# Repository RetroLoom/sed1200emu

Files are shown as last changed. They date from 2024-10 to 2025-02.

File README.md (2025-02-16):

# SED1200Emu
This Emulator is intended to replace hard-to-obtain Epson SED1200 based LCD modules with common HD44780 ones. The original project page can be found here http://sensi.org/~tnt23/sed1200emu/index.html. The original goal is for having a replacement LCD for the Roland MT-32, but the display could be adapted for other projects. All attempts to reach the original designer have failed. Please reach out to me if you have any information about this. 

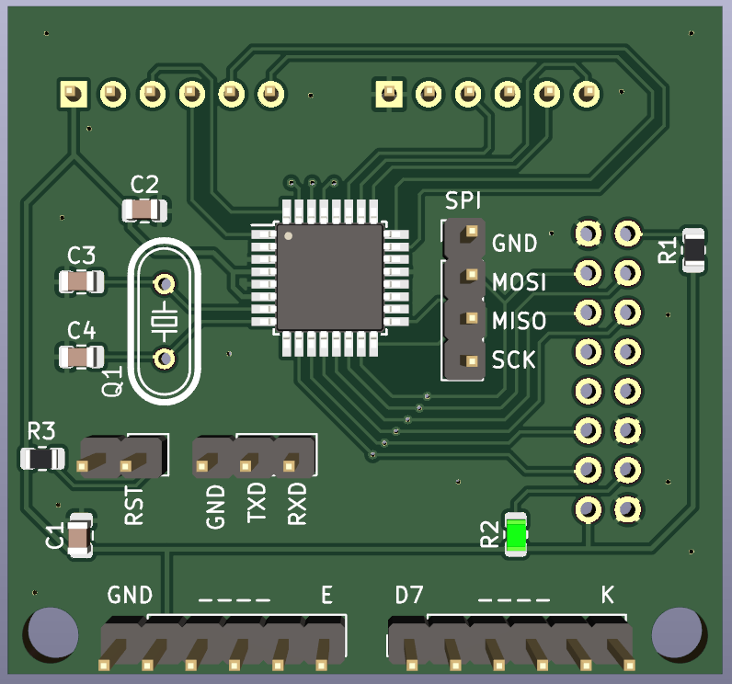
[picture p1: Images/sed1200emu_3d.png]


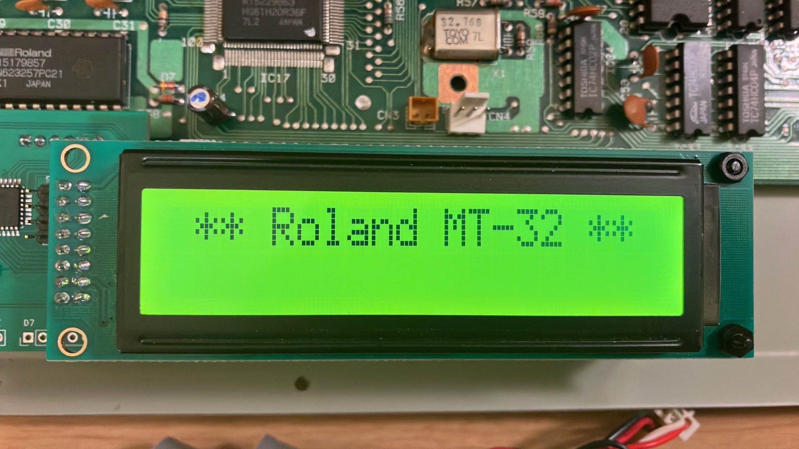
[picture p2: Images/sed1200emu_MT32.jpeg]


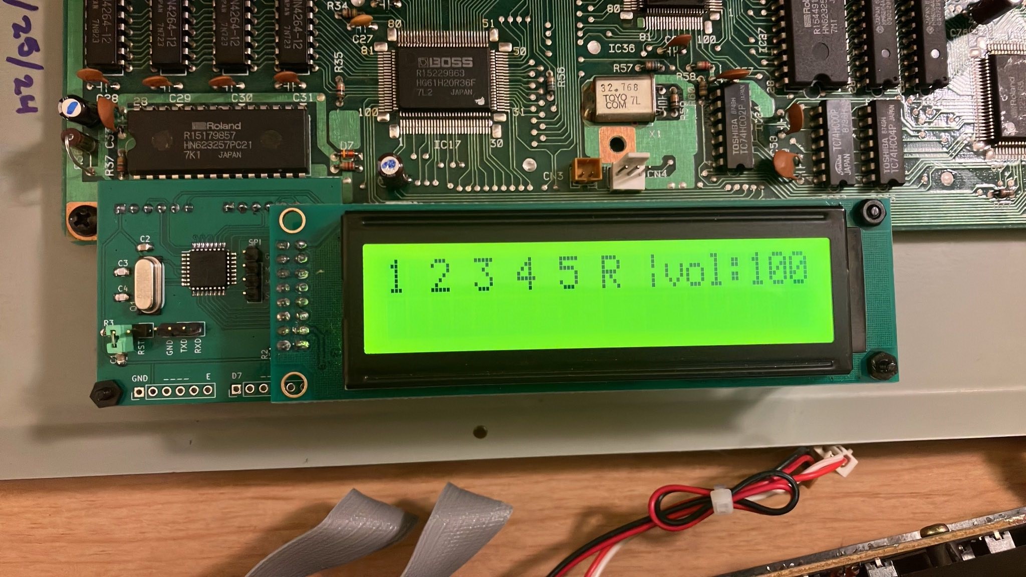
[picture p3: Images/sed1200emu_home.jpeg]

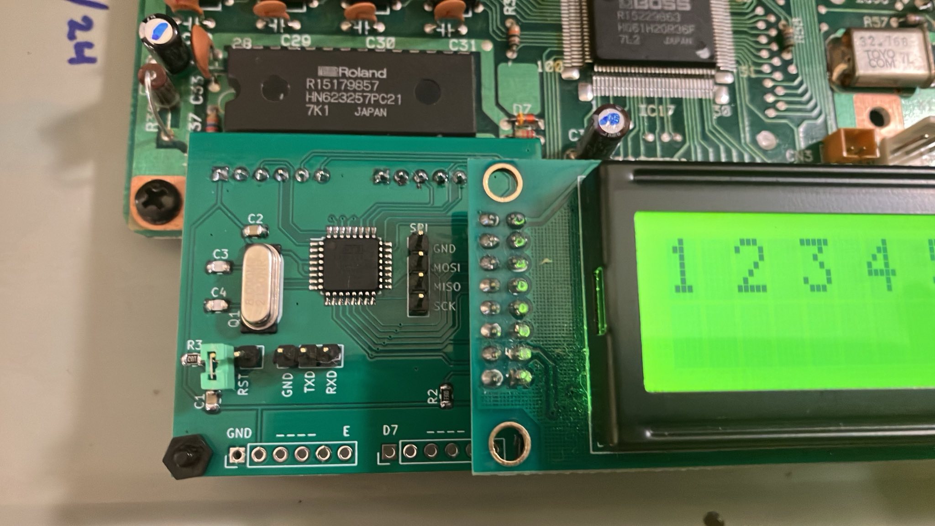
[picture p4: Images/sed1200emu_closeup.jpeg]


## Building and Installation
The main driver and translator for this project is an ATMEGA8L-8AU which can still be purchased on popular sites like Mouser and Digi-key. This IC may become obsolete, so the intention is to adapt as they become less available. The gerber files, BOM, Binary HEX files will also be provided as they become current and available. All current releases are in beta, and come with no warranty. 

### ATMEGA8 Flashing
When programming the ATMEGA8 it is important to use the correct configuration. This will enable the external clocks and any other flags needed for binary to run correctly. 

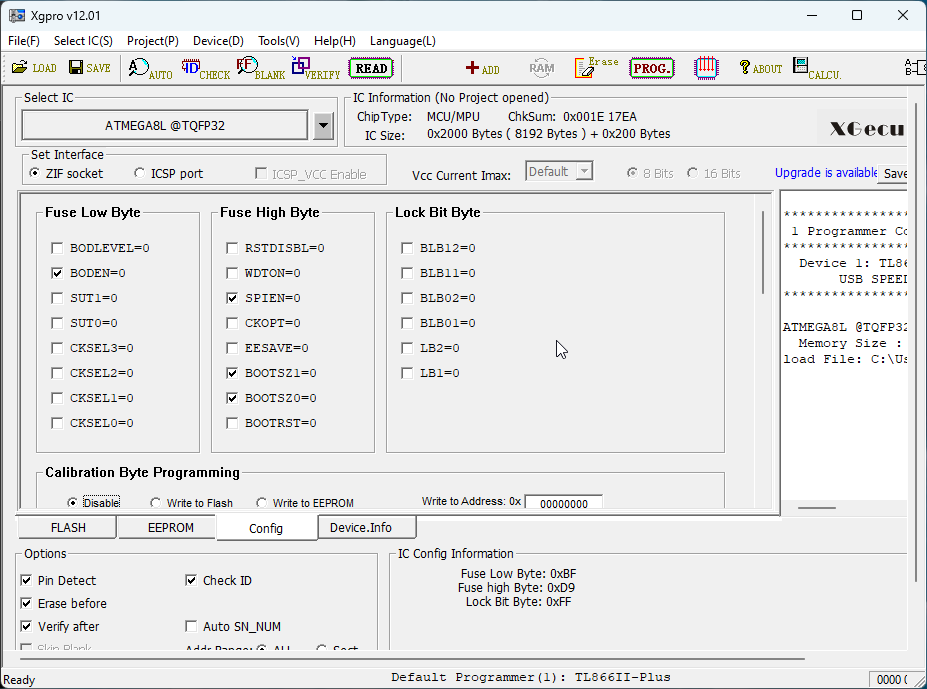
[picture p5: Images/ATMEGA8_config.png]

Fuse Low Byte: 0xBF

Fuse High Bte: 0xD9

Lock Bit Byte: 0xFF

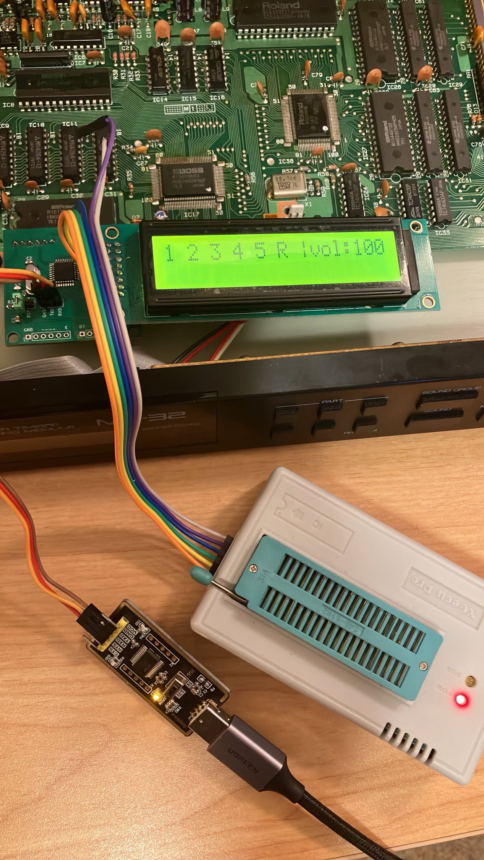
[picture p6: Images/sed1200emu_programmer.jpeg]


### Compiling
Download and install WinAVR for minimum compiling support. Using command prompt or windows powershell, run make in the src directory.

Note: You can optionally replace the AVR compiling files to manually update to newer versions. 

### UART Config
For debugging or logging display message, connect via serial to GND, TXD, RXD at 9600 baud.
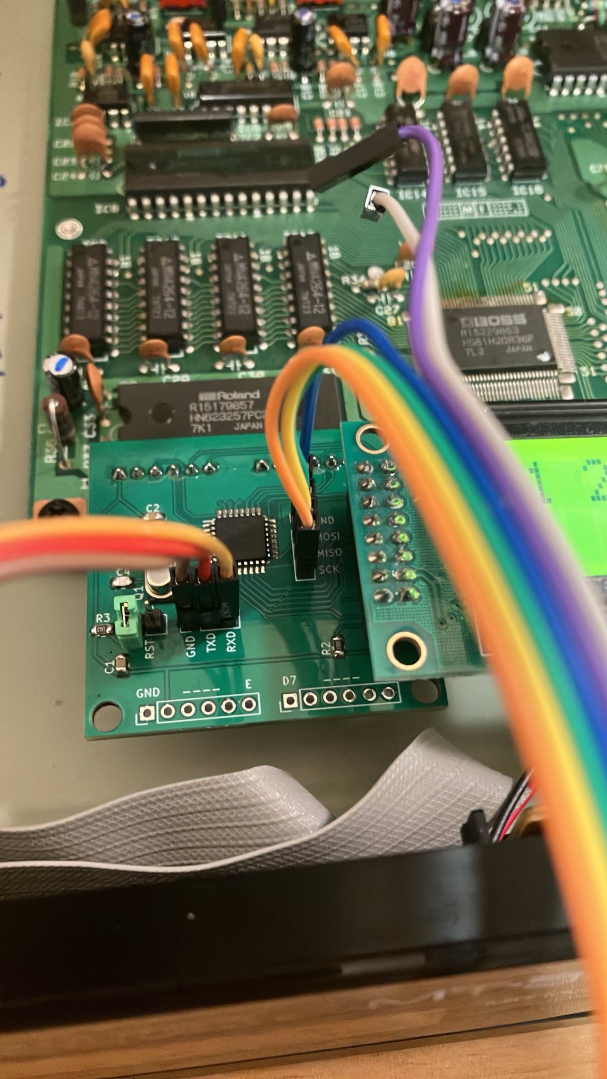
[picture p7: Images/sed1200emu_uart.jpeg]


UART Serial out display clone (and debugging).



### Optional Headers
There are three headers that are considered optional, but recommended if you are developing or want to reprogram the ATMEGA8 after it is soldered to the board. The SPI header will provide connection for flashing, and the UART header will give you access to feedback and debug information for code development. 

## Development Notes
At the moment, 20x2 HD44780 LCD is too large as a direct replacement for the MT-32. Adaptation will be needed in the form of a redesigned 3D printed face plate for the current LCD. If you have interest in helping design something like this, please get in touch! I have searched around for better fitting 20x2 LCD's but I have not found anything that would match. 

Another option is to program new methods that adapts the display to a 16x2 LCD. This might need some elaborate programming to work. 

## License Information
The original release this project is derived from Tim Tashpulatov without license or warranty. The updated revisions of this project released in 2024 include a GPL v3 license which can be found here in the LICENSE file. 

Source code and software license - [GPL v3](https://github.com/skadarnold/sed1200emu/blob/master/LICENSE)

Hardware design license - [CERN OHL-S](https://ohwr.org/project/cernohl/-/wikis/uploads/819d71bea3458f71fba6cf4fb0f2de6b/cern_ohl_s_v2.txt)

## Support the Developer
This project is brought to you free and open source, but it is not free to develop. If you like this project please consider supporting this and future developments. 

https://www.patreon.com/RetroLoom

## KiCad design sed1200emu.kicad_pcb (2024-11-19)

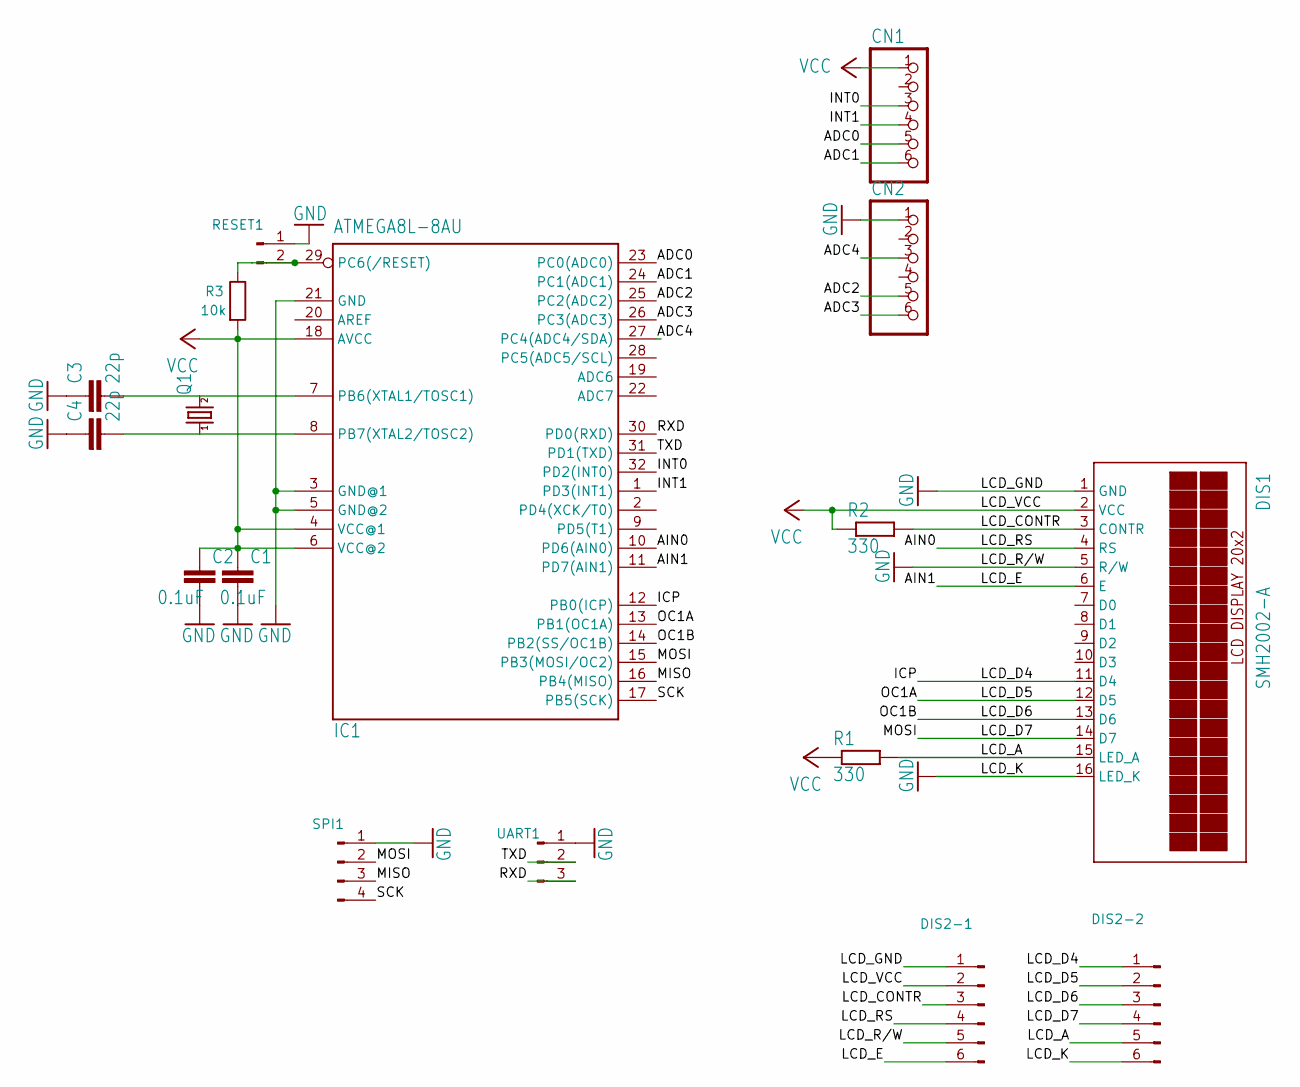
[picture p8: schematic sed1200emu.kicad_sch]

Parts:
C1, C2: 0.1uF; C_0805_2012Metric
C3, C4: 22p; C_0805_2012Metric
CN1, CN2: Conn_01x06_Pin 2.54mm; PinHeader_1x06_P2.54mm_Vertical
DIS1: SMH2002-A; TUXGR_20X2
DIS2-1, DIS2-2: Conn_01x06_Pin; PinHeader_1x06_P2.54mm_Vertical
IC1: ATMEGA8L-8AU; TQFP-32_7x7mm_P0.8mm
Q1: HC-49/S 16pF; HC49_S
R1, R2: 330; R_0805_2012Metric
R3: 10k; R_0805_2012Metric
RESET1: Conn_01x02_Pin; PinHeader_1x02_P2.54mm_Vertical
SPI1: Conn_01x04_Pin; PinHeader_1x04_P2.54mm_Vertical
UART1: Conn_01x03_Pin; PinHeader_1x03_P2.54mm_Vertical

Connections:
/ADC0: CN1.5, IC1.23 (PC0(ADC0))
/ADC1: CN1.6, IC1.24 (PC1(ADC1))
/ADC2: CN2.5, IC1.25 (PC2(ADC2))
/ADC3: CN2.6, IC1.26 (PC3(ADC3))
/ADC4: CN2.3, IC1.27 (PC4(ADC4/SDA))
/AIN0: DIS1.4 (RS), DIS2-1.4, IC1.10 (PD6(AIN0))
/AIN1: DIS1.6 (E), DIS2-1.6, IC1.11 (PD7(AIN1))
/ICP: DIS1.11 (D4), DIS2-2.1, IC1.12 (PB0(ICP))
/INT0: CN1.3, IC1.32 (PD2(INT0))
/INT1: CN1.4, IC1.1 (PD3(INT1))
/LCD_A: DIS1.15 (LED_A), DIS2-2.5, R1.2
/LCD_CONTR: DIS1.3 (CONTR), DIS2-1.3, R2.2
/LCD_D5: DIS1.12 (D5), DIS2-2.2, IC1.13 (PB1(OC1A))
/LCD_D6: DIS1.13 (D6), DIS2-2.3, IC1.14 (PB2(SS/OC1B))
/LCD_D7: DIS1.14 (D7), DIS2-2.4, IC1.15 (PB3(MOSI/OC2)), SPI1.2
/MISO: IC1.16 (PB4(MISO)), SPI1.3
/RXD: IC1.30 (PD0(RXD)), UART1.3
/SCK: IC1.17 (PB5(SCK)), SPI1.4
/TXD: IC1.31 (PD1(TXD)), UART1.2
GND: C1.2, C2.2, C3.1, C4.1, CN2.1, DIS1.1 (GND), DIS1.5 (R/W), DIS1.16 (LED_K), DIS2-1.1, DIS2-1.5, DIS2-2.6, IC1.3 (GND@1), IC1.5 (GND@2), IC1.21 (GND), RESET1.1, SPI1.1, UART1.1
unnamed: C3.2, IC1.7 (PB6(XTAL1/TOSC1)), Q1.2
unnamed: C4.2, IC1.8 (PB7(XTAL2/TOSC2)), Q1.1
unnamed: IC1.29 (PC6(/RESET)), R3.1, RESET1.2
VCC: C1.1, C2.1, CN1.1, DIS1.2 (VCC), DIS2-1.2, IC1.4 (VCC@1), IC1.6 (VCC@2), IC1.18 (AVCC), R1.1, R2.1, R3.2

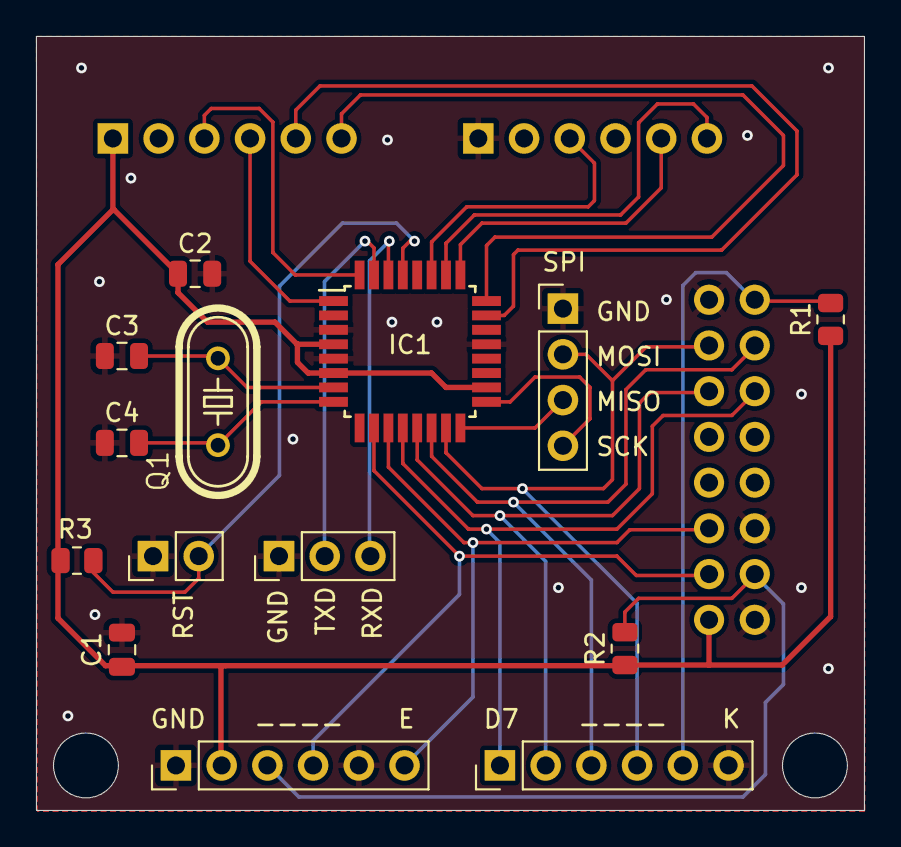
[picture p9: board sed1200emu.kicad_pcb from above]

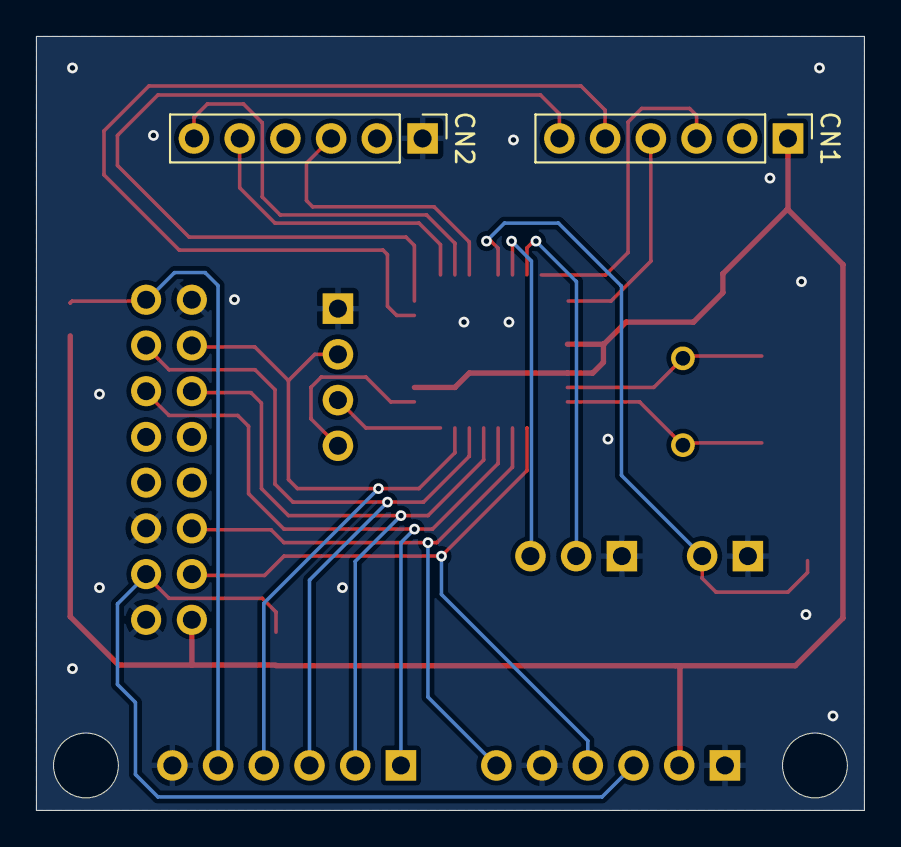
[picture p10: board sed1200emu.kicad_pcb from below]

Board: 2 copper layers, 46.0 x 43.0 mm, 17 parts (2 on the bottom side), 24 nets.

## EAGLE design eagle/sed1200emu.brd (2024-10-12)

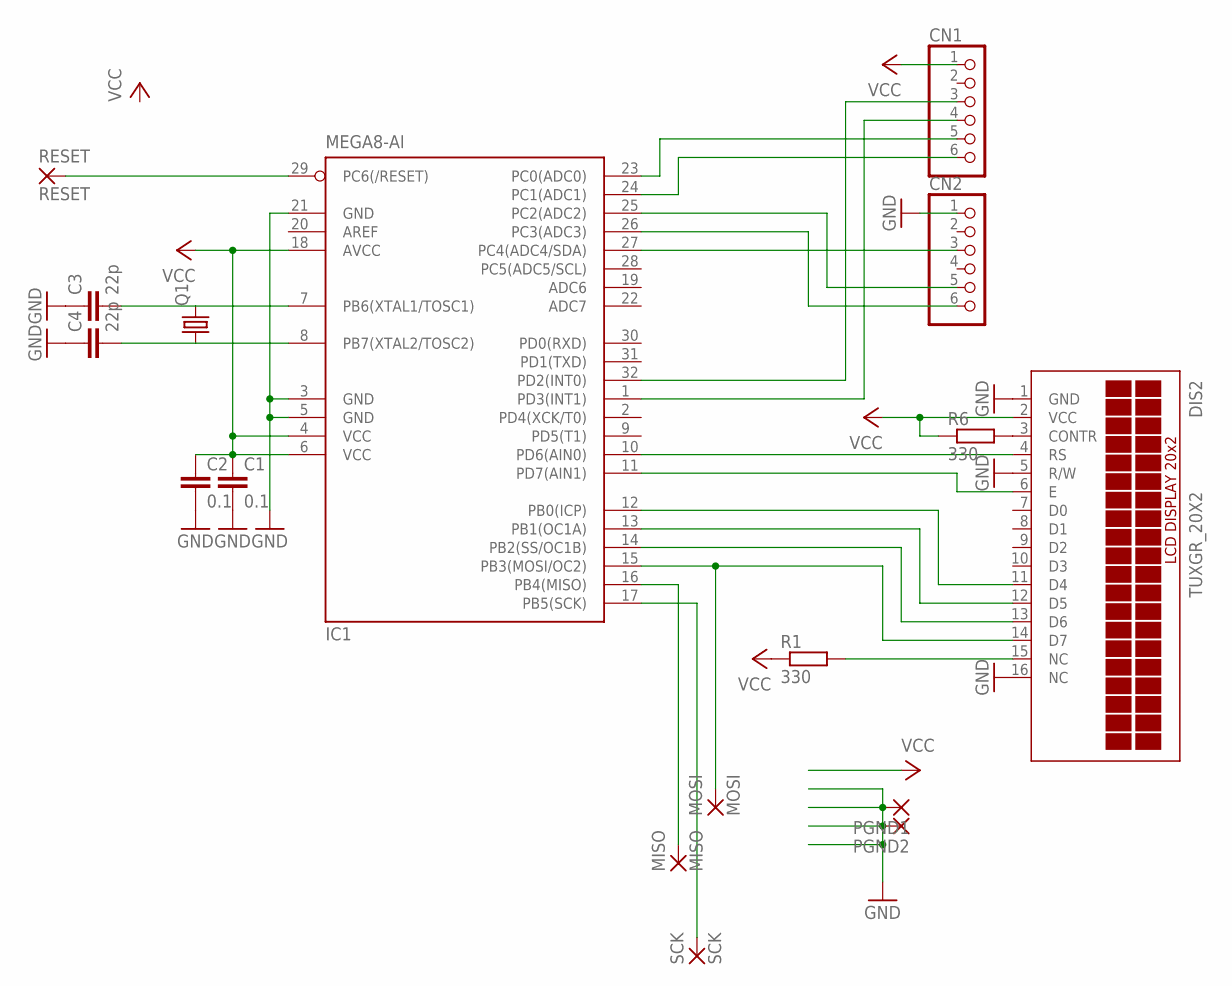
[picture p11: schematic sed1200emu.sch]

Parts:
C1, C2: 0.1; C0805
C3, C4: 22p; C0805
CN1, CN2: PINHD-1X6; 1X06
DIS2: TUXGR_20X2
IC1: MEGA8-AI; TQFP32-08
MISO: MISO; 2,15/1,0
MOSI: MOSI; 2,15/1,0
PGND1, PGND2: 2,15/1,0
Q1: CRYSTALHC49S; HC49/S
R1, R6: 330; M0805
RESET: RESET; 2,15/1,0
SCK: SCK; 2,15/1,0

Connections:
GND: C1.2, C2.2, C3.1, C4.1, CN2.1, DIS2.1 (GND), DIS2.5 (R/W), DIS2.16 (NC), IC1.3 (GND), IC1.5 (GND), IC1.21 (GND), PGND1.1, PGND2.1
unnamed: CN2.3, IC1.27 (PC4(ADC4/SDA))
unnamed: CN1.5, IC1.23 (PC0(ADC0))
unnamed: CN1.6, IC1.24 (PC1(ADC1))
unnamed: CN2.5, IC1.25 (PC2(ADC2))
unnamed: IC1.29 (PC6(/RESET)), RESET.1
unnamed: CN2.6, IC1.26 (PC3(ADC3))
unnamed: DIS2.15 (NC), R1.2
unnamed: DIS2.6 (E), IC1.11 (PD7(AIN1))
unnamed: C3.2, IC1.7 (PB6(XTAL1/TOSC1)), Q1.2
unnamed: DIS2.4 (RS), IC1.10 (PD6(AIN0))
unnamed: C4.2, IC1.8 (PB7(XTAL2/TOSC2)), Q1.1
unnamed: DIS2.3 (CONTR), R6.2
unnamed: DIS2.11 (D4), IC1.12 (PB0(ICP))
unnamed: DIS2.12 (D5), IC1.13 (PB1(OC1A))
unnamed: DIS2.13 (D6), IC1.14 (PB2(SS/OC1B))
unnamed: DIS2.14 (D7), IC1.15 (PB3(MOSI/OC2)), MOSI.1
unnamed: IC1.16 (PB4(MISO)), MISO.1
unnamed: IC1.17 (PB5(SCK)), SCK.1
PS2CLK: CN1.3, IC1.32 (PD2(INT0))
PS2DATA: CN1.4, IC1.1 (PD3(INT1))
VCC: C1.1, C2.1, CN1.1, DIS2.2 (VCC), IC1.4 (VCC), IC1.6 (VCC), IC1.18 (AVCC), R1.1, R6.1

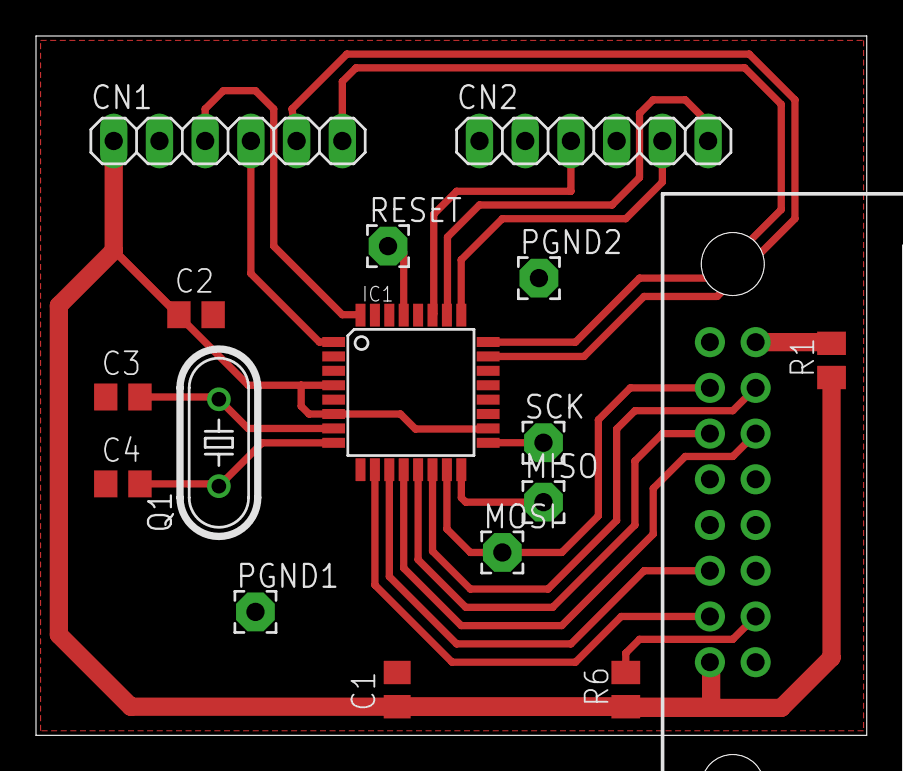
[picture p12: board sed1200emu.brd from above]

Board: 2 copper layers, 46.2 x 38.9 mm, 17 parts (0 on the bottom side), 22 nets.

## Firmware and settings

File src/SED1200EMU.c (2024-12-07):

#include <avr/io.h>
#include <avr/interrupt.h>
#include <util/delay.h>

#include <stdio.h>
#include <stdlib.h>
#include <stdint.h>

#include "atmega.h"
#include "lcd.h"
#include "tables.h"
#include "uart.h"

volatile uint8_t SEDBuffer [2][20];
volatile uint8_t SEDRow = 0, SEDCol = 0;
uint8_t address = 0;
extern volatile uint8_t queueHead, queueTail;

int8_t bufferDisplay = 0;

void updateDisplay()
{
    // Draw buffer to display
	uint8_t row;
    for (row = 0; row < 2; row++)  // Iterate both rows
    {
        // Set the cursor to the start of the current row
        uint8_t cursorPos = (row == 0 ? 0x00 : 0x40);  // DDRAM addresses
        LCD_SendCmd(LCD_SET_CURSOR | cursorPos);
        
        // Draw each column in the row
		uint8_t col;
        for (col = 0; col < LCD_COLS; col++)
        {
            uint8_t c = SEDBuffer[row][col];
            //if (c == 0x00) {
            //	c = ASCII_SPACE;  // Replace NULL bytes with spaces
            //}
            LCD_SendChar(c);  // Send character to display
        }
	}
}

int main () 
{
	UART_Init();
	ATMEGA_Init();
	LCD_Init ();
		
	// Display initial message after initialization
	LCD_Home ();
	LCD_SendStr(" ** Roland MT-32 ** "); 
	//LCD_ScrollStr("                    ** Roland MT-32 **                    ", 0, 300, 20);  // 300ms delay for scrolling speed
    _delay_ms(2000);

	// program CGRAM symbol 00
    LCD_SendCmd(CGRAM1_SET);
    LCD_SendChar(CGRAM_ON); LCD_SendChar(CGRAM_ON); LCD_SendChar(CGRAM_ON);
    LCD_SendChar(CGRAM_OFF); LCD_SendChar(CGRAM_ON); LCD_SendChar(CGRAM_ON);
    LCD_SendChar(CGRAM_ON); LCD_SendChar(CGRAM_OFF);

	while (1)
	{
		// Check if there is data in the queue
		if (queueHead != queueTail)
		{
			// Dequeue the next character or command to process
			uint8_t c = LCD_Dequeue();

			// Check if the dequeued byte is a command for the LCD
			if ((c & 0xC0) == LCD_SET_CURSOR)
			{								// Check if top two bits of `c` are `10` (indicating a cursor set command)
				address = c & 0x3F; // Extract the DDRAM address (lower 6 bits)

				// UART
				if (address == 0)
						UART_HideCursor();
	
				if (uartDebug)
				{
					if (address == 0x11)
						UART_NextRow();

					UART_SendStr(" (C%d) ", address);
				}
				else										
					UART_GotoY(address);

				// Send the command to set the cursor position to this address
				LCD_SendCmd(LCD_SET_CURSOR | address); // Send the cursor position command to the LCD

				// Determine the row and column based on the address
				if (address < 0x40)
				{ // Row 0
					SEDRow = 0;
					SEDCol = address; // Column is the address itself for Row 0
				}
				else
				{ // Row 1
					SEDRow = 1;
					SEDCol = address - 0x40; // Subtract 0x40 to get the column in Row 1
				}
			}
			else
			{
				switch (c)
				{
				case 0x02:
					c = CGRAM1;
					break;

				case 0x01:
					c = 0xff; // Convert 0x01 to 0xff (special character in CGRAM)
					break;

				case 0x7c:
					c = CGRAM1;
					break;

				default:
					// No conversion needed for other values of c
					break;
				}

				if (!bufferDisplay)
				{
					if (address < 20)
						LCD_SendChar(c);
				}
				else
					SEDBuffer[SEDRow][SEDCol] = c;

				// Move the cursor within the buffer for the next character
				if (++SEDCol >= 20)
				{ // Wrap to the next line if at the end of the row
					SEDCol = 0;
					SEDRow = (SEDRow + 1) % 2; // Toggle between Row 0 and Row 1
				}
			}

			// Check if the command involves turning on the cursor
			if ((c & 0x0e) == 0x0e)
			{ // Check if bits 1-3 of `c` match the cursor-on command for the SED1200
				// Send the equivalent HD44780 command to turn on the cursor
				LCD_SendCmd(0x0d | ((c & 0x01) << 1)); // Map cursor setting to HD44780 format
			}
		}
		else
		{
			//if ((millis - SEC_LAST_UPDATE) >= 2000)
			//{
			//	SEC_SHOW = 0;
			//}

			if (bufferDisplay)
				updateDisplay();

			//LCD_GotoXY (1,15);
			//LCD_SendStr ("%d", millis);			
		}
	}
}

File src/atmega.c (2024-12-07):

/*
 * This file is part of the SED1200EMU Project.
 *
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
 * You should have received a copy of the GNU General Public License
 * along with this program. If not, see <https://www.gnu.org/licenses/>.
 */

#include <avr/io.h>
#include <avr/interrupt.h>
#include <util/delay.h>

#include <string.h>
#include <stdio.h>
#include <stdlib.h>
#include <stdint.h>

#include "atmega.h"
#include "lcd.h"
#include "tables.h"
#include "uart.h"

uint8_t xlat [16] = {
	0b0000, 0b1000, 0b0010, 0b1010,
	0b0100, 0b1100, 0b0110, 0b1110,
	0b0001, 0b1001, 0b0011, 0b1011,
	0b0101, 0b1101, 0b0111, 0b1111
};

volatile uint8_t sed_byte;
volatile uint8_t rs;
volatile uint8_t count_e;

volatile uint32_t millis = 0; // Millisecond counter, volatile because it's modified in ISR

void ATMEGA_Init()
{
    // PORT B
	// ---------------------------
	// PB3		(LCD) D7		o
	// PB2		(LCD) D6		o
	// PB1		(LCD) D5		o
	// PB0		(LCD) D4		o

	DDRB =	0xF;

	// PORT C
	// ---------------------------
	// PC4		(SED1200) RS	i
	// PC3		(SED1200) D0	i
	// PC2		(SED1200) D2	i
	// PC1		(SED1200) D1	i
	// PC0		(SED1200) D3	i

	DDRC = 0;

	// PORT D
	// --------------------------
	// PD7		(LCD) E			o
	// PD6		(LCD) RS 		o
	// PD3		(SED1200) E 	i aka INT1
	// PD2		(SED1200) CS 	i aka INT0

	DDRD = 0xC0;

	MCUCR = _BV(ISC11) | _BV(ISC10) |		// 11 - INT1 rising edge
			_BV(ISC01);						// 10 - INT0 falling edge

	GICR = _BV(INT1) | _BV(INT0);			// enable INT1 and INT0

    //Timer0_Init();
	Timer1_Init();
	//Timer2_Init();

    sei ();
}

void Timer0_Init() {
    // Timer0 Configuration for Compare Match mode
    OCR0 = 249;  // Set the compare match value (adjust as needed)
    TCCR0 = (1 << WGM01) | (1 << CS02) | (1 << CS00);  // CTC mode, prescaler clk/1024
    TIMSK |= (1 << OCIE0);  // Enable Timer0 compare match interrupt
}

void Timer1_Init() {
    /* Set up Timer1 for 1 ms overflow
    TCCR1A = 0;                     // Set Timer1 to normal mode
    TCCR1B = (1 << WGM12) | (1 << CS11); // CTC mode, prescaler of 8
    OCR1A = 999;                    // Output compare match value for 1ms at 8 MHz/8 prescaler
    TIMSK = (1 << OCIE1A);         // Enable output compare A match interrupt
	*/

	// Set up Timer1 for direct updateDisplay()
	TCCR1B |= (1 << WGM12);      // Configure Timer1 in CTC mode
    TCCR1B |= (1 << CS11) | (1 << CS10); // Set prescaler to 64
    OCR1A = 12500;               // Set compare value for 100 ms interval
    TIMSK |= (1 << OCIE1A);      // Enable Timer1 compare match A interrupt
	//

	/* Set up Timer1 for a 1-second interval
	TCCR1A = 0;				// Set Timer1 to normal mode (CTC)
	TCCR1B |= (1 << WGM12); // Configure Timer1 in CTC mode
	TCCR1B |= (1 << CS12);	// Set prescaler to 256
	OCR1A = 31249;			// Compare value for 1 second interval at 8 MHz / 256 prescaler
	TIMSK |= (1 << OCIE1A); // Enable Timer1 compare match A interrupt
	*/
}

void Timer2_Init() {
	// Set up Timer2 for 1ms overflow (8-bit timer)
	TCCR2 = (1 << WGM21) | (1 << CS21); // CTC mode, prescaler of 8
	OCR2 = 249;							// Output compare match value for 1ms at 8 MHz/8 prescaler
	TIMSK |= (1 << OCIE2);				// Enable output compare A match interrupt
}

//ISR(TIMER0_COMPA_vect) 
//{
        
        /*
		lcdIdx ++;
		
		if (lcdIdx >= 40)
			lcdIdx = 0;

		if (lcdIdx == 0)
			LCD_SendCmd (0x80);

		if (lcdIdx == 20)
			LCD_SendCmd (0xc0);
		*/

		//LCD_SendChar (LCDBuffer [lcdIdx]);
		
		//updateDisplay();
//}

// Timer1 compare match ISR, triggers every 1 ms
ISR(TIMER1_COMPA_vect) {
    millis += 100;
    //updateDisplay();
}

//ISR(TIMER2_COMPA_vect) {
//    millis++;
//}

ISR(INT0_vect) {
	count_e = 0;
}

ISR(INT1_vect) {
	//sei ();
	

	if (!(count_e & 0x01)) {
		// upper data D7...D4
		sed_byte = xlat [(PINC & 0x0f)] << 4;
	}
	else {
		// lower data D3...D0
		sed_byte |= xlat [(PINC & 0x0f)];
		rs = PINC & _BV(PC4);		

		if (rs) {
			// data
			LCD_Enqueue (sed_byte);
		}
		else {
			// command
			switch (sed_byte & 0xc0) {				
				case 0x80:
					LCD_Enqueue (sed_byte);
					break;
				case 0xc0:
					LCD_Enqueue (0x80 + 10 + (sed_byte & 0x3f));
					break;
				default:
					break;

			}

//			if ((sed_byte & 0xc0) == 0x80) {	// SET CURSOR ADDR
//				LCD_Enqueue (sed_byte);
//			}
		}	
	}

	count_e ++;
	
}

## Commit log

2024-10-12 sed1200emu Init
    [sed1200emu.brd, sed1200emu.kicad_pcb, sed1200emu.kicad_sch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]
2024-10-12 Change TUXGR_20X2 Mask / Through hole cuts to User Drawings
    [sed1200emu.kicad_pcb]
2024-10-12 Replace MEGA8 Symbol and Footprint
    [sed1200emu.kicad_pcb, sed1200emu.kicad_sch]
2024-10-12 Replace CN1 and CN2 with KiCad Symbols
    [sed1200emu.kicad_pcb, sed1200emu.kicad_sch]
2024-10-12 Replace all 1pin out headers to KiCad Symbols
    [sed1200emu.kicad_pcb, sed1200emu.kicad_sch]
2024-10-12 Net class trace changes
    [sed1200emu.kicad_pcb]
2024-10-12 Update 20X2 Display Symbol & and fix pin header references
    [sed1200emu.kicad_pcb, sed1200emu.kicad_sch]
2024-10-12 Clean trace and connections
    [sed1200emu.kicad_pcb]
2024-10-12 Fix Clearance and Design Rule Violations
    [sed1200emu.kicad_pcb]
2024-10-12 Fix all TUXGR_20X2 Silkscreen/ Cuts to User Layer
    [sed1200emu.kicad_pcb]
2024-10-12 Fix more Rule Violations
    [sed1200emu.kicad_pcb]
2024-10-12 Add Ground Vias
    [sed1200emu.kicad_pcb]
2024-10-12 Update Reference Values for BOM
    [sed1200emu.kicad_pcb, sed1200emu.kicad_sch]
2024-11-19 Initial sectioning and timer
2024-11-19 Experimental Section Triggers
    None of this is working the way I was expecting, so I am ditching it. However I would like to save my work in a commit in case I ever need to refer back to it for some reason.
2024-11-19 Cleanup PCB, Add UART header, Consolidate SPI headers, Reset VCC Connect
    [sed1200emu.kicad_pcb, sed1200emu.kicad_sch]
2024-11-19 Cleanup edge cuts and fill zones
    [sed1200emu.kicad_pcb]
2024-11-19 Add standoff holes for bottom support
    [sed1200emu.kicad_pcb]
2024-11-19 Added single row HD44780 header, shifted all components up to make better use of space
    [sed1200emu.kicad_pcb, sed1200emu.kicad_sch]
2024-11-19 Add gerber files
    [sed1200emu-B_Cu.gbr, sed1200emu-B_Mask.gbr, sed1200emu-B_Paste.gbr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]
2024-12-05 Configure UART
2024-12-05 Update Binary HEX for UART
2024-12-07 Expand and enhance UART
    Terminal clones display of the MT32. Raised baud rate for smoother refreshing rates. Debug mode for log mode.
2024-12-07 UART Display clean up and bug fixes, limit character display to < 20
    [SED1200EMU.c, uart.c]
2024-12-07 UART Receive on vector, receiving updates, fix vertical bar
    [SED1200EMU.c, uart.c]

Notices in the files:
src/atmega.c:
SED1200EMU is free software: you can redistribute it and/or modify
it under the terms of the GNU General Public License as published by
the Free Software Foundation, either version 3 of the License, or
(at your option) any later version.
